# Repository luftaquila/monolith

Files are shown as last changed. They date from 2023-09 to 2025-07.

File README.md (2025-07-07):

> [!IMPORTANT]
> Monolith [v2](https://github.com/luftaquila/monolith/tree/v2) is now under development and will be released in a few months!

# monolith

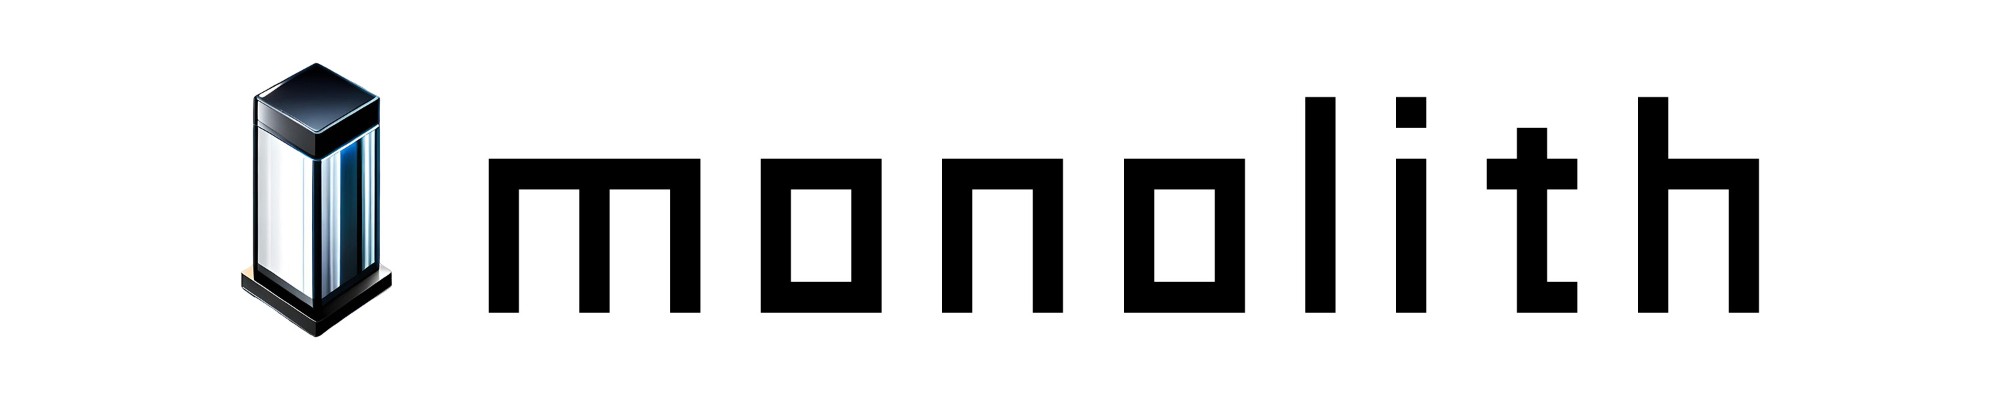
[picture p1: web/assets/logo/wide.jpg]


<div align="center">
<strong>
<samp>

[English](README.md) · [한국어](README_KO.md)

</samp>
</strong>
</div>

Monolith is an open-source DIY datalogging platform for the Student Formula and Baja.

Build your own datalogger and use the real-time telemetry and data analysis tools with ease!

### Main Features
* Various types of data supported, including CAN, acceleration, GPS, digital/analog signals and wheel speeds
* Micro SD card support
* Real-time telemetry
* Real world time tracking via RTC
* Web based data visualization and analysis tools

### [Documentation](https://github.com/luftaquila/monolith/wiki)

Monolith consists of `TMA-1` datalogger, `TMA-2` telemetry monitor and `TMA-3` data analysis tools.

<br>

## TMA-1 Datalogger
TMA-1 is an onboard device that gathers data from the car. It can record the following data:

* CAN 2.0(A/B) bus traffic
* 8-channel digital input signals
* 4-channel analog input signals
* 4-channel external wheel speed sensors (digital pulse period)
* 3-axis ±4g acceleration (ADXL345)
* GPS informations (NEO-6/7M)
* Supply voltage(LV) and internal CPU temperature
* Real world time(RTC)

Refer to the [TMA‐1 Features and Usage Guide](https://github.com/luftaquila/monolith/wiki/%5BEN%5D-TMA%E2%80%901-Features-and-Usage-Guide) for detailed explanations about each feature.

### 1-1. TMA-1 Do It Yourself!
TMA-1 is a DIY datalogger that each user buys components and builds their own device. It is designed with commercial modules and through-hole components for easy self build.

Required components and build instructions are described in the [TMA-1 DIY Guide](https://github.com/luftaquila/monolith/wiki/%5BEN%5D-TMA%E2%80%901-DIY-Guide).



### 1-2. TMA-1 Configuration Tool
This is a GUI tool that builds and uploads the firmware to the TMA-1 with configured features.

With this tool, you can activate features in the datalogger, synchronize TMA-1's clock to your computer time, and configure the networks for the telemetry.

For the detailed information, please refer to the [TMA-1 Configuration Tool Guide](https://github.com/luftaquila/monolith/wiki/%5BEN%5D-TMA%E2%80%901-Configuration-Tool-Guide).



<br><br>

## TMA-2 Telemetry monitor
TMA-2 consists of the telemetry server that TMA-1 communicates with, and the web client for real-time data monitoring.

### Server
Users do not need to set up the server individually, except in case you want your own server. TMA-1 uses the default monolith server (monolith.luftaquila.io) for the telemetry.

> The default TMA-2 server is available to the approved users only.<br>
> There are no additional fees for registration. Just send me a school and team name, your desired car ID and key to mail@luftaquila.io and that's it.

If you want to self-host your own server, follow the [TMA-2 Server Setup Guide](https://github.com/luftaquila/monolith/wiki/%5BEN%5D-TMA%E2%80%902-Server-Setup-Guide).

### Client
Real-time monitoring client is served at https://monolith.luftaquila.io/live.

Each user can set up their own UI with their preferences. It also supports the UI export and import features.

For the detailed information, please refer to the [TMA‐2 Client Usage Guide](https://github.com/luftaquila/monolith/wiki/%5BEN%5D-TMA%E2%80%902-Client-Usage-Guide).



<br><br>

## TMA-3 Log Translator and Data Analysis Tool
TMA-1 datalogger stores the log in the SD card in a binary format, according to the predefined [protocol](https://github.com/luftaquila/monolith/wiki/%5BEN%5D-Log-Protocol).

TMA-3 is a set of tools that can translate binary logs to human-readable format(JSON/CSV) and visualize the collected data into graphs and a map.

All these features are web application services that can be instantly accessed at https://monolith.luftaquila.io.

For the detailed information, please refer to the [TMA‐3 Data Analysis Tool Guide](https://github.com/luftaquila/monolith/wiki/%5BEN%5D-TMA%E2%80%903-Data-Analysis-Tool-Guide).



<br><br>

## Others
The name of the project was inspired by Arthur C. Clark's novel *2001: A Space Odyssey*.

Monolith received the Gold Award in the *2023 KSAE KSAE Baja/Formula/EV* Technology Idea section and the Best Award in the *2022-2 Ajou University SW Convergence Challenge*.



<br><br>

## Sponsors


Prototype PCB of the TMA-1 was sponsored by [PCBWay](https://www.pcbway.com/).

<br>

## LICENSE
```
"THE BEERWARE LICENSE" (Revision 42):
LUFT-AQUILA wrote this project. As long as you retain this notice,
you can do whatever you want with this stuff. If we meet someday,
and you think this stuff is worth it, you can buy me a beer in return.
```

<br>

<hr>

<picture>
  <source media="(prefers-color-scheme: dark)" srcset="https://api.star-history.com/svg?repos=luftaquila/monolith&type=Date&theme=dark" />
  <source media="(prefers-color-scheme: light)" srcset="https://api.star-history.com/svg?repos=luftaquila/monolith&type=Date" />
  Star History Chart
</picture>

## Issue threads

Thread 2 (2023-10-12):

Broken log data is transferred

luftaquila, 2023-10-12:
After a random period of time since TMA-1 boot, TMA-2 server is receiving misaligned log packets.

example 1) timestamp 4847271
`a7f64900030200eb0000000000000000` to `000bf749000302005000000000000000`

example 2) timestamp 854379
`6b090d0003030049ffffc20200000000` to `00ca090d00030200e500000000000000`

One byte is inserted in front of the log packet and causing parse failure.

After a long time of operation, there are two invalid bytes in front of the log byte.

They looks like the last bytes of the previous log packet in the buffer.

example logs:
```
{"channel":"default","data":{"checksum":true,"datetime":null,"key":"ACCELEROMETER_DATA","level":"INFO","parsed":{"x":-0.0078125,"y":0.0703125,"z":1.046875},"raw":[255,255,9,0,134,0,0,0],"source":"ACCELEROMETER","timestamp":4847171,"value":575526273023},"id":"3XQem_L0JusMWR-oAAAD","ip":"192.168.0.1","level":"info","message":"REPORT","raw":"43f6490003050017ffff090086000000","timestamp":"2023-10-12 20:10:22.187"}
{"channel":"default","data":{"checksum":true,"datetime":null,"key":"DIGITAL_DATA","level":"INFO","parsed":{"DIN0":0,"DIN1":0,"DIN2":0,"DIN3":0,"DIN4":0,"DIN5":0,"DIN6":0,"DIN7":0},"raw":[0,0,0,0,0,0,0,0],"source":"DIGITAL","timestamp":4847271,"value":0},"id":"3XQem_L0JusMWR-oAAAD","ip":"192.168.0.1","level":"info","message":"REPORT","raw":"a7f64900030200eb0000000000000000","timestamp":"2023-10-12 20:10:22.274"}
{"channel":"default","data":"TypeError: Cannot read properties of undefined (reading 'name')","id":"3XQem_L0JusMWR-oAAAD","ip":"192.168.0.1","level":"error","message":"PARSE FAILED","raw":"000bf749000302005000000000000000","timestamp":"2023-10-12 20:10:22.377"}
{"channel":"default","data":"TypeError: Cannot read properties of undefined (reading 'name')","id":"3XQem_L0JusMWR-oAAAD","ip":"192.168.0.1","level":"error","message":"PARSE FAILED","raw":"0010f7490003030005ffffaf02000000","timestamp":"2023-10-12 20:10:22.384"}
```

```
{"channel":"default","data":{"checksum":true,"datetime":null,"key":"DIGITAL_DATA","level":"INFO","parsed":{"DIN0":0,"DIN1":0,"DIN2":0,"DIN3":0,"DIN4":0,"DIN5":0,"DIN6":0,"DIN7":0},"raw":[0,0,0,0,0,0,0,0],"source":"DIGITAL","timestamp":854374,"value":0},"id":"OwGVzEw9kGCz46YnAAAl","ip":"192.168.0.1","level":"info","message":"REPORT","raw":"66090d00030200810000000000000000","timestamp":"2023-10-13 00:07:33.290"}
{"channel":"default","data":{"checksum":true,"datetime":null,"key":"ANALOG_SYS","level":"INFO","parsed":{"CPU_TEMP":6553.5,"INPUT_VOLTAGE":4.551501831501831},"raw":[255,255,194,2,0,0,0,0],"source":"ANALOG","timestamp":854379,"value":46333951},"id":"OwGVzEw9kGCz46YnAAAl","ip":"192.168.0.1","level":"info","message":"REPORT","raw":"6b090d0003030049ffffc20200000000","timestamp":"2023-10-13 00:07:33.297"}
{"channel":"default","data":"TypeError: Cannot read properties of undefined (reading 'name')","id":"OwGVzEw9kGCz46YnAAAl","ip":"192.168.0.1","level":"error","message":"PARSE FAILED","raw":"00ca090d00030200e500000000000000","timestamp":"2023-10-13 00:07:33.384"}
{"channel":"default","data":"TypeError: Cannot read properties of undefined (reading 'name')","id":"OwGVzEw9kGCz46YnAAAl","ip":"192.168.0.1","level":"error","message":"PARSE FAILED","raw":"00ca090d000303019d8a00af0204046f","timestamp":"2023-10-13 00:07:33.392"}
```

luftaquila, 2023-10-13:
This is a problem of ESP32, not STM32.

I2C bus is transmitting a normal log with fine align, while server is receiving misaligned data.

I2C records:
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

Server logs:
```
{"channel":"default","data":"TypeError: Cannot read properties of undefined (reading 'name')","id":"5eaiSrF9_m9ZKYgVAAAs","ip":"192.168.0.1","level":"error","message":"PARSE FAILED","raw":"0444ab5b00030500cef7ff0000860000","timestamp":"2023-10-13 19:43:26.401"}
{"channel":"default","data":"TypeError: Cannot read properties of undefined (reading 'name')","id":"5eaiSrF9_m9ZKYgVAAAs","ip":"192.168.0.1","level":"error","message":"PARSE FAILED","raw":"00a8ab5b00030200b300000000000000","timestamp":"2023-10-13 19:43:26.486"}
{"channel":"default","data":"TypeError: Cannot read properties of undefined (reading 'name')","id":"5eaiSrF9_m9ZKYgVAAAs","ip":"192.168.0.1","level":"error","message":"PARSE FAILED","raw":"00a8ab5b00030301a57700e1020e0480","timestamp":"2023-10-13 19:43:26.493"}
{"channel":"default","data":"TypeError: Cannot read properties of undefined (reading 'name')","id":"5eaiSrF9_m9ZKYgVAAAs","ip":"192.168.0.1","level":"error","message":"PARSE FAILED","raw":"04a8ab5b0003050033f7ff0000870000","timestamp":"2023-10-13 19:43:26.501"}
{"channel":"default","data":"TypeError: Cannot read properties of undefined (reading 'name')","id":"5eaiSrF9_m9ZKYgVAAAs","ip":"192.168.0.1","level":"error","message":"PARSE FAILED","raw":"000cac5b000302001800000000000000","timestamp":"2023-10-13 19:43:26.586"}
{"channel":"default","data":"TypeError: Cannot read properties of undefined (reading 'name')","id":"5eaiSrF9_m9ZKYgVAAAs","ip":"192.168.0.1","level":"error","message":"PARSE FAILED","raw":"000cac5b00030301a5b2002e0324047c","timestamp":"2023-10-13 19:43:26.593"}
{"channel":"default","data":"TypeError: Cannot read properties of undefined (reading 'name')","id":"5eaiSrF9_m9ZKYgVAAAs","ip":"192.168.0.1","level":"error","message":"PARSE FAILED","raw":"040eac5b000305009af7ff0000870000","timestamp":"2023-10-13 19:43:26.601"}
{"channel":"default","data":"TypeError: Cannot read properties of undefined (reading 'name')","id":"5eaiSrF9_m9ZKYgVAAAs","ip":"192.168.0.1","level":"error","message":"PARSE FAILED","raw":"0070ac5b000302007c00000000000000","timestamp":"2023-10-13 19:43:26.687"}
{"channel":"default","data":"TypeError: Cannot read properties of undefined (reading 'name')","id":"5eaiSrF9_m9ZKYgVAAAs","ip":"192.168.0.1","level":"error","message":"PARSE FAILED","raw":"0070ac5b00030301af8000bc02ca0322","timestamp":"2023-10-13 19:43:26.694"}
{"channel":"default","data":"TypeError: Cannot read properties of undefined (reading 'name')","id":"5eaiSrF9_m9ZKYgVAAAs","ip":"192.168.0.1","level":"error","message":"PARSE FAILED","raw":"0470ac5b00030500fcf7ff0000870000","timestamp":"2023-10-13 19:43:26.701"}
```

luftaquila, 2023-10-13:
Proved no misaligning happens while running alive for 10,000,000ms(166min)

Closed 2023-10-13.

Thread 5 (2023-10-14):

Wrong internal CPU temperature measurement

luftaquila, 2023-10-14:
In `ANALOG_SYS` log data, internal cpu temperature is always stored [255, 255] when TMA-1 is powered by 12V VIN input, causing 6553.5°C CPU temperature.

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

But when TMA-1 is powered by USB-C in ESP32 board, it is stored correctly.

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

luftaquila, 2023-10-29:
seems like problem of casting in internal temperature calculation at [here](https://github.com/luftaquila/monolith/blob/main/device/TMA-1/Core/Src/adc.c#L35C5-L35C114)

```c
adc_sys_value[0] = (uint16_t)(((110.0 - 30) * (adc_sys_value[0] - TS_CAL1) / (TS_CAL2 - TS_CAL1) + 30) * 10);
```

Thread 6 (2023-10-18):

Poor TMA-3 graph viewer performance

luftaquila, 2023-10-18:
TMA-3 is currently using Chart.js for graph viewer, which has poor performance for large data points

Replace Chart.js to [Dygraphs](https://dygraphs.com/) for better graph performance.

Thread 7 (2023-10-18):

Missing support for CAN bitwise data view

luftaquila, 2023-10-18:
Currently TMA-2/3 does not support CAN bitwise data parsing and favorite data feature, while UI supports.

luftaquila, 2023-10-19:
Decided to drop support for CAN favorite data feature (ee746b1bb2287862ee7f3cd8c8767a61d54dbb44)

Closed 2025-08-12.

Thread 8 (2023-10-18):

Fixed CAN baud rate

luftaquila, 2023-10-18:
Current TMA-1 has 250 kbit/s fixed CAN baud rate.

Support for flexible baud rate: 125 kbit/s, 250 kbit/s, 500 kbit/s, 1Mbit/s is needed.

Closed 2023-10-19.

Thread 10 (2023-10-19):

Wireless log file transmit feature

luftaquila, 2023-10-19:
Currently, the only way to analyze data saved in the TMA-1's SD card is to eject and put the card into the computer, and upload it to the TMA-3.

Ejecting a card is the most annoying step of the procedure. Anyway, TMA-1 has a wireless internet connection.

So TMA-1 can transfer a saved log file to the TMA-3 over wireless when requested.

Feature idea:
1. TMA-3 requests a log file list
2. TMA-2 server requests TMA-1 to send a log file list
3. ESP32 receives the request and informs STM32 about the request (by an additional wire `ESP_REQ`)
4. STM32 enters log transmitting mode, aborting all data logging job and disabling all interrupts
5. STM32 reads the SD card and transmits the log file list to ESP32 via I2C
6. ESP32 hand out the log file list to TMA-2, and TMA-2 passes the list to TMA-3
7. A specific log file transfer request made by TMA-3 is sent to ESP32 through the TMA-2
8. ESP32 requests STM32 to transmit the specific log file
9. STM32 transmit the log file to ESP32 via I2C. The log file will be sliced into chunks since ESP32 cannot hold the whole log file in a memory.
10.  ESP32 transfers the log file chunk to TMA-2
11. TMA-2 assembles the log file and pass it to the TMA-3

luftaquila, 2025-08-12:
Done in v2

Closed 2025-08-12.

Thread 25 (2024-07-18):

ESP32 firmware build fails with esp32-arduino core package version >= 3.0.0

luftaquila, 2024-07-18:
Link error occurs while building esp32 firmware. https://github.com/luftaquila/monolith/discussions/24

Build fails with following versions:
```
Used library        Version Path
Wire                3.0.3   C:\monolith\builder\toolchain\arduino\data\packages\esp32\hardware\esp32\3.0.3\libraries\Wire
WiFi                3.0.3   C:\monolith\builder\toolchain\arduino\data\packages\esp32\hardware\esp32\3.0.3\libraries\WiFi
Networking          3.0.3   C:\monolith\builder\toolchain\arduino\data\packages\esp32\hardware\esp32\3.0.3\libraries\Network
RingBuffer          1.0.5   C:\monolith\builder\toolchain\arduino\user\libraries\RingBuffer
ArduinoJson         7.1.0   C:\monolith\builder\toolchain\arduino\user\libraries\ArduinoJson
WebSockets          2.4.1   C:\monolith\builder\toolchain\arduino\user\libraries\WebSockets
NetworkClientSecure 3.0.3   C:\monolith\builder\toolchain\arduino\data\packages\esp32\hardware\esp32\3.0.3\libraries\NetworkClientSecure

Used platform Version Path
esp32:esp32   3.0.3   C:\monolith\builder\toolchain\arduino\data\packages\esp32\hardware\esp32\3.0.3
```

Build succeed with following versions:
```
Used library     Version Path
Wire             2.0.0   C:\monolith\builder\toolchain\arduino\data\packages\esp32\hardware\esp32\2.0.17\libraries\Wire
WiFi             2.0.0   C:\monolith\builder\toolchain\arduino\data\packages\esp32\hardware\esp32\2.0.17\libraries\WiFi
RingBuffer       1.0.5   C:\monolith\builder\toolchain\arduino\user\libraries\RingBuffer
ArduinoJson      7.1.0   C:\monolith\builder\toolchain\arduino\user\libraries\ArduinoJson
WebSockets       2.4.1   C:\monolith\builder\toolchain\arduino\user\libraries\WebSockets
WiFiClientSecure 2.0.0   C:\monolith\builder\toolchain\arduino\data\packages\esp32\hardware\esp32\2.0.17\libraries\WiFiClientSecure

Used platform Version Path
esp32:esp32   2.0.17  C:\monolith\builder\toolchain\arduino\data\packages\esp32\hardware\esp32\2.0.17
```

Not sure which side causes the error, `esp32-arduino` or `arduino-cli`.

Closed 2024-07-18.

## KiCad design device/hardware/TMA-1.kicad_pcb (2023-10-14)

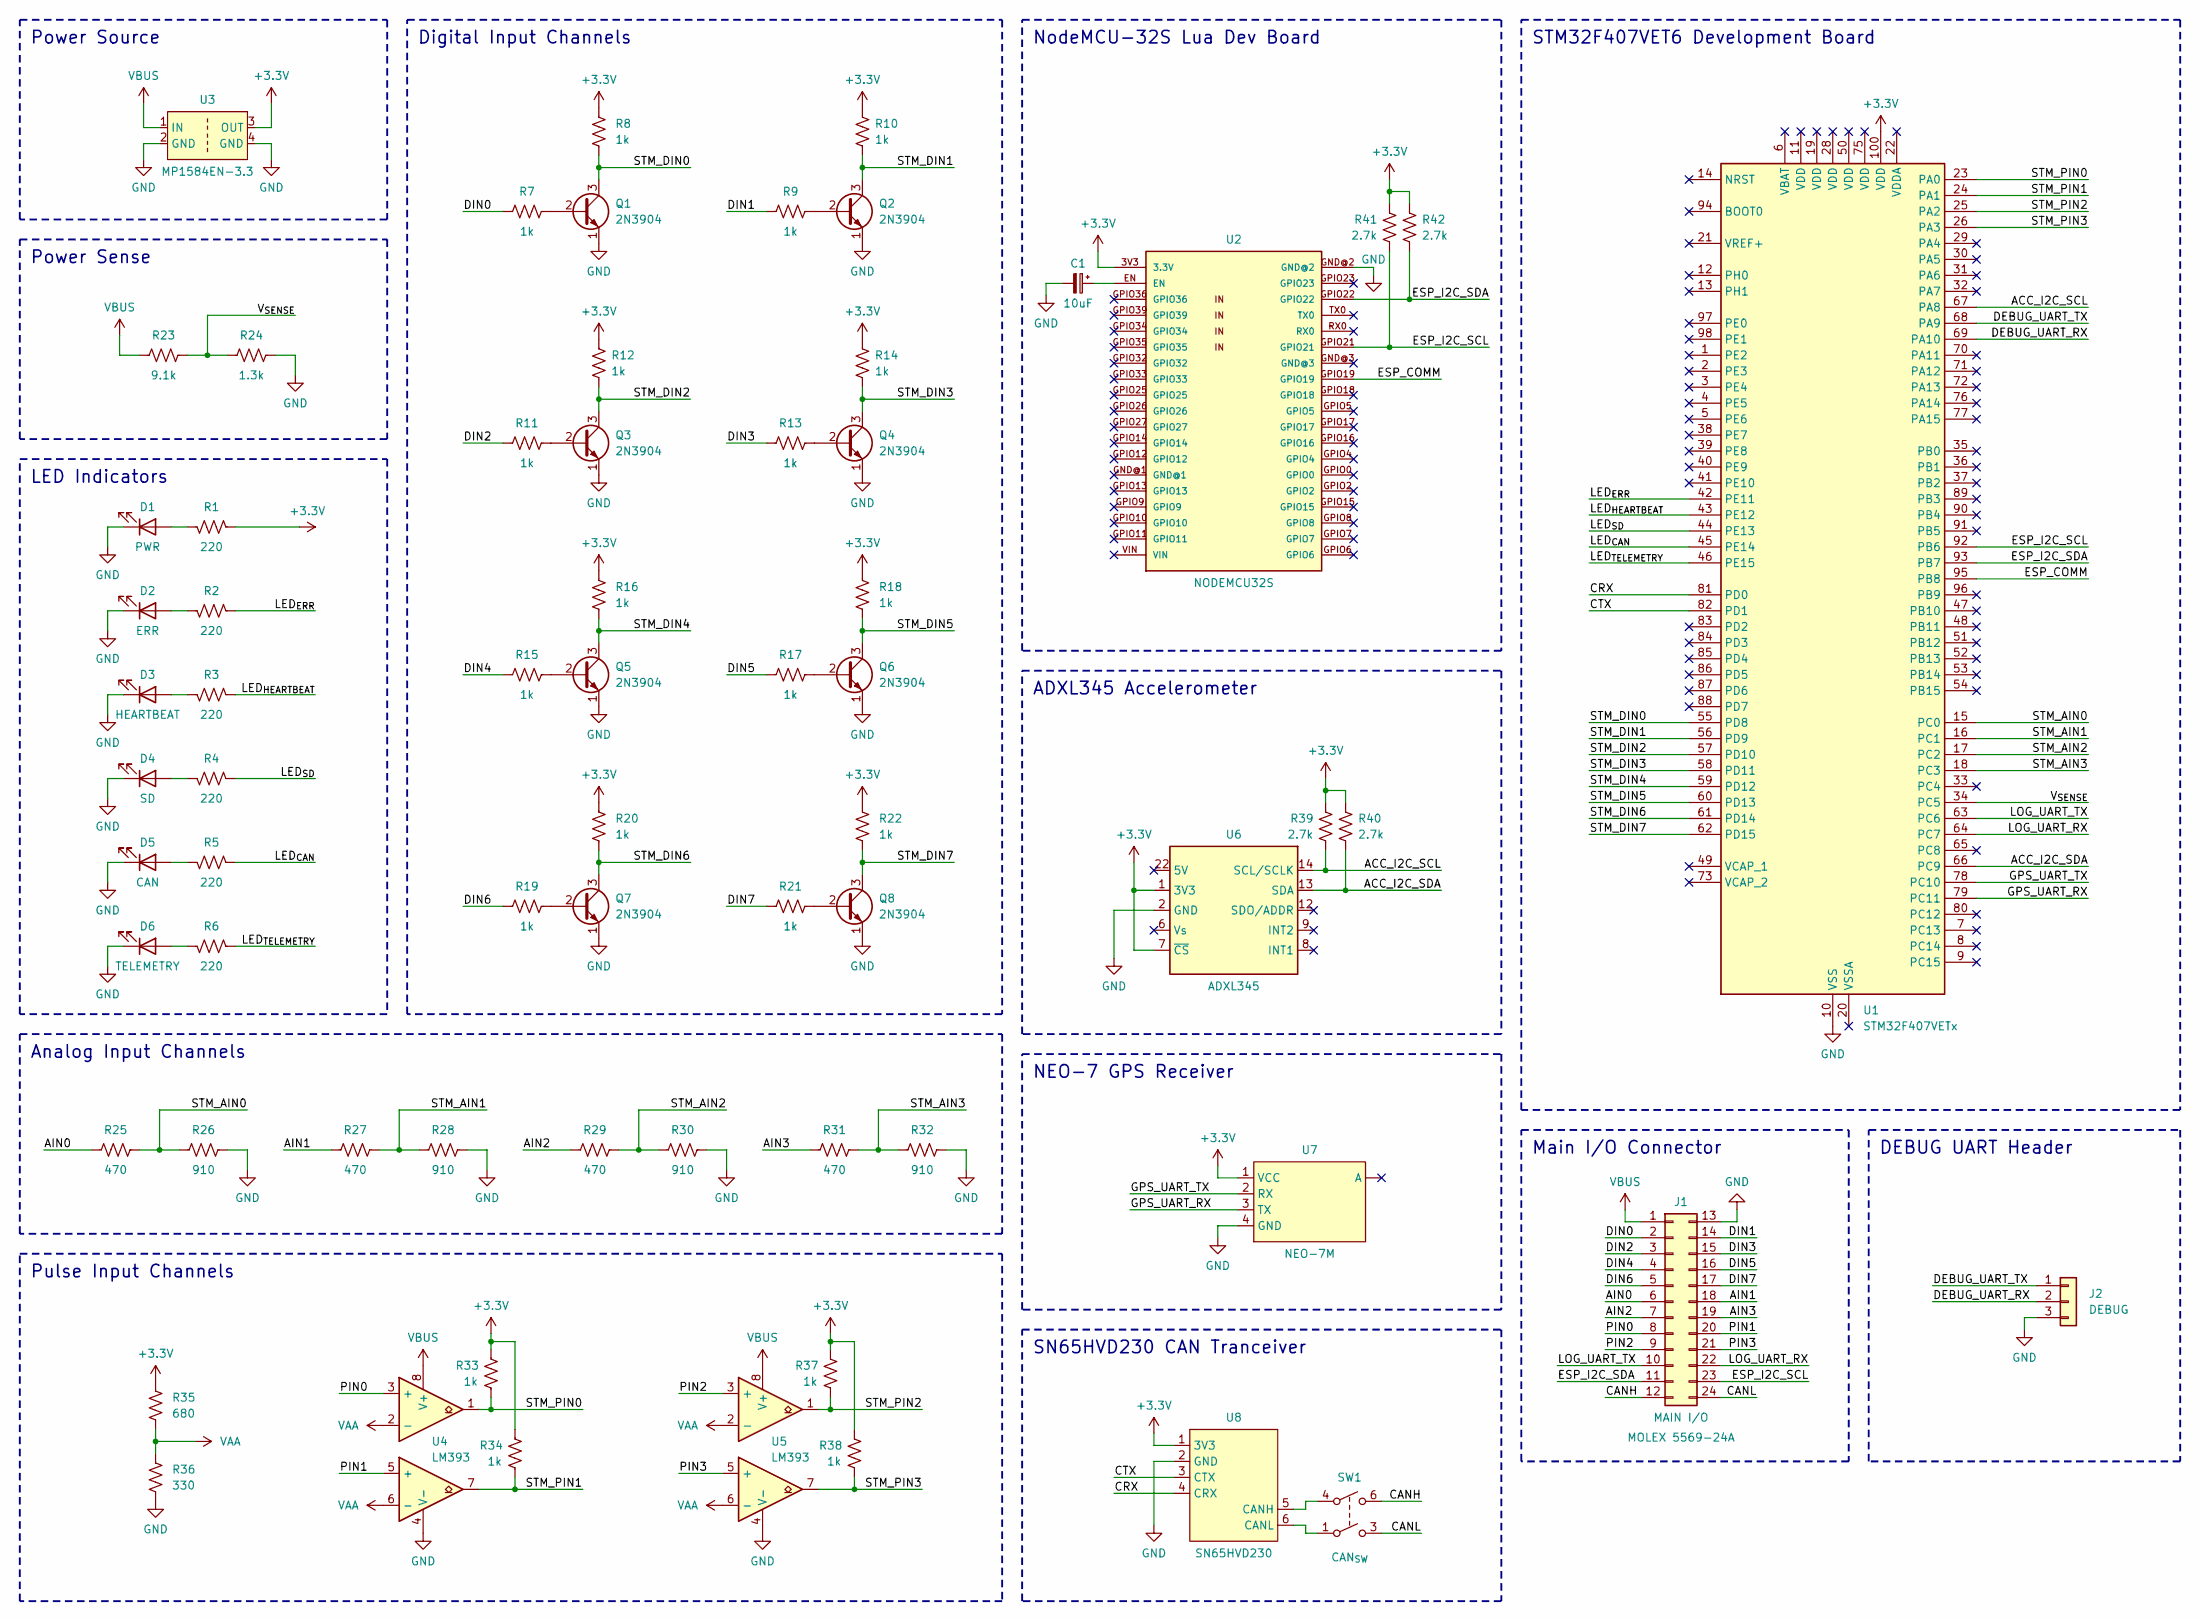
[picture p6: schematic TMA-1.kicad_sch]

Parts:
C1: 10uF; CP_Radial_D5.0mm_P2.00mm
D1: PWR; LED_D5.0mm_FlatTop
D2: ERR; LED_D5.0mm_FlatTop
D3: HEARTBEAT; LED_D5.0mm_FlatTop
D4: SD; LED_D5.0mm_FlatTop
D5: CAN; LED_D5.0mm_FlatTop
D6: TELEMETRY; LED_D5.0mm_FlatTop
J1: MAIN I/O; Molex_Mini-Fit_Jr_5569-24A1_2x12_P4.20mm_Horizontal
J2: DEBUG; PinHeader_1x03_P2.54mm_Vertical
Q1, Q2, Q3, Q4, Q5, Q6, Q7, Q8: 2N3904; TO-92_Inline_Wide
R1, R2, R3, R4, R5, R6: 220; R_Axial_DIN0207_L6.3mm_D2.5mm_P10.16mm_Horizontal
R7, R8, R9, R10, R11, R12, R13, R14, R15, R16, R17, R18, R19, R20, R21, R22, R33, R34, R37, R38: 1k; R_Axial_DIN0207_L6.3mm_D2.5mm_P10.16mm_Horizontal
R23: 9.1k; R_Axial_DIN0207_L6.3mm_D2.5mm_P10.16mm_Horizontal
R24: 1.3k; R_Axial_DIN0207_L6.3mm_D2.5mm_P10.16mm_Horizontal
R25, R27, R29, R31: 470; R_Axial_DIN0207_L6.3mm_D2.5mm_P10.16mm_Horizontal
R26, R28, R30, R32: 910; R_Axial_DIN0207_L6.3mm_D2.5mm_P10.16mm_Horizontal
R35: 680; R_Axial_DIN0207_L6.3mm_D2.5mm_P10.16mm_Horizontal
R36: 330; R_Axial_DIN0207_L6.3mm_D2.5mm_P10.16mm_Horizontal
R39, R40, R41, R42: 2.7k; R_Axial_DIN0207_L6.3mm_D2.5mm_P10.16mm_Horizontal
SW1: CAN_{SW}; TOGGLE_SWITCH
U1: STM32F407VETx; STM32F407_HOLDER
U2: NODEMCU32S
U3: MP1584EN-3.3; MP1584EN_MODULE
U4, U5: LM393; DIP-8_W7.62mm
U6: ADXL345; ADXL345_MODULE
U7: NEO-7M; GPS_MODULE
U8: SN65HVD230; SN65HVD230_MODULE

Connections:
+3.3V: R1.1, R8.1, R10.1, R12.1, R14.1, R16.1, R18.1, R20.1, R22.1, R33.1, R34.1, R35.1, R37.1, R38.1, R39.1, R40.1, R41.1, R42.1, U1.100 (VDD), U2.3V3 (3.3V), U3.3 (OUT), U6.1 (3V3), U6.7 (~CS), U7.1 (VCC), U8.1 (3V3)
/ACC_I2C_SCL: R39.2, U1.67 (PA8), U6.14 (SCL/SCLK)
/ACC_I2C_SDA: R40.2, U1.66 (PC9), U6.13 (SDA)
/AIN0: J1.6, R25.1
/AIN1: J1.18, R27.1
/AIN2: J1.7, R29.1
/AIN3: J1.19, R31.1
/CANH: J1.12, SW1.6
/CANL: J1.24, SW1.3
/CRX: U1.81 (PD0), U8.4 (CRX)
/CTX: U1.82 (PD1), U8.3 (CTX)
/DEBUG_UART_RX: J2.2, U1.69 (PA10)
/DEBUG_UART_TX: J2.1, U1.68 (PA9)
/DIN0: J1.2, R7.1
/DIN1: J1.14, R9.1
/DIN2: J1.3, R11.1
/DIN3: J1.15, R13.1
/DIN4: J1.4, R15.1
/DIN5: J1.16, R17.1
/DIN6: J1.5, R19.1
/DIN7: J1.17, R21.1
/ESP_COMM: U1.95 (PB8), U2.GPIO19
/ESP_I2C_SCL: J1.23, R41.2, U1.92 (PB6), U2.GPIO21
/ESP_I2C_SDA: J1.11, R42.2, U1.93 (PB7), U2.GPIO22
/GPS_UART_RX: U1.79 (PC11), U7.3 (TX)
/GPS_UART_TX: U1.78 (PC10), U7.2 (RX)
/LED_{CAN}: R5.1, U1.45 (PE14)
/LED_{ERR}: R2.1, U1.42 (PE11)
/LED_{HEARTBEAT}: R3.1, U1.43 (PE12)
/LED_{SD}: R4.1, U1.44 (PE13)
/LED_{TELEMETRY}: R6.1, U1.46 (PE15)
/LOG_UART_RX: J1.22, U1.64 (PC7)
/LOG_UART_TX: J1.10, U1.63 (PC6)
/PIN0: J1.8, U4.3 (+)
/PIN1: J1.20, U4.5 (+)
/PIN2: J1.9, U5.3 (+)
/PIN3: J1.21, U5.5 (+)
/STM_AIN0: R25.2, R26.1, U1.15 (PC0)
/STM_AIN1: R27.2, R28.1, U1.16 (PC1)
/STM_AIN2: R29.2, R30.1, U1.17 (PC2)
/STM_AIN3: R31.2, R32.1, U1.18 (PC3)
/STM_DIN0: Q1.3 (C), R8.2, U1.55 (PD8)
/STM_DIN1: Q2.3 (C), R10.2, U1.56 (PD9)
/STM_DIN2: Q3.3 (C), R12.2, U1.57 (PD10)
/STM_DIN3: Q4.3 (C), R14.2, U1.58 (PD11)
/STM_DIN4: Q5.3 (C), R16.2, U1.59 (PD12)
/STM_DIN5: Q6.3 (C), R18.2, U1.60 (PD13)
/STM_DIN6: Q7.3 (C), R20.2, U1.61 (PD14)
/STM_DIN7: Q8.3 (C), R22.2, U1.62 (PD15)
/STM_PIN0: R33.2, U1.23 (PA0), U4.1
/STM_PIN1: R34.2, U1.24 (PA1), U4.7
/STM_PIN2: R37.2, U1.25 (PA2), U5.1
/STM_PIN3: R38.2, U1.26 (PA3), U5.7
/V_{SENSE}: R23.2, R24.1, U1.34 (PC5)
GND: C1.2, D1.1 (K), D2.1 (K), D3.1 (K), D4.1 (K), D5.1 (K), D6.1 (K), J1.13, J2.3, Q1.1 (E), Q2.1 (E), Q3.1 (E), Q4.1 (E), Q5.1 (E), Q6.1 (E), Q7.1 (E), Q8.1 (E), R24.2, R26.2, R28.2, R30.2, R32.2, R36.2, U1.10 (VSS), U1.27 (VSS), U1.74 (VSS), U1.99 (VSS), U2.GND@2, U3.2 (GND), U3.4 (GND), U4.4 (V-), U5.4 (V-), U6.2 (GND), U7.4 (GND), U8.2 (GND)
unnamed: C1.1, U2.EN
unnamed: D1.2 (A), R1.2
unnamed: D2.2 (A), R2.2
unnamed: D3.2 (A), R3.2
unnamed: D4.2 (A), R4.2
unnamed: D5.2 (A), R5.2
unnamed: D6.2 (A), R6.2
unnamed: Q1.2 (B), R7.2
unnamed: Q2.2 (B), R9.2
unnamed: Q3.2 (B), R11.2
unnamed: Q4.2 (B), R13.2
unnamed: Q5.2 (B), R15.2
unnamed: Q6.2 (B), R17.2
unnamed: Q7.2 (B), R19.2
unnamed: Q8.2 (B), R21.2
unnamed: SW1.4, U8.5 (CANH)
unnamed: SW1.1, U8.6 (CANL)
VAA: R35.2, R36.1, U4.2 (-), U4.6 (-), U5.2 (-), U5.6 (-)
VBUS: J1.1, R23.1, U3.1 (IN), U4.8 (V+), U5.8 (V+)

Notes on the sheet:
LED Indicators
Power Source
Main I/O Connector
Digital Input Channels
STM32F407VET6 Development Board
DEBUG UART Header
NEO-7 GPS Receiver
Power Sense
Analog Input Channels
Pulse Input Channels
ADXL345 Accelerometer
SN65HVD230 CAN Tranceiver
NodeMCU-32S Lua Dev Board

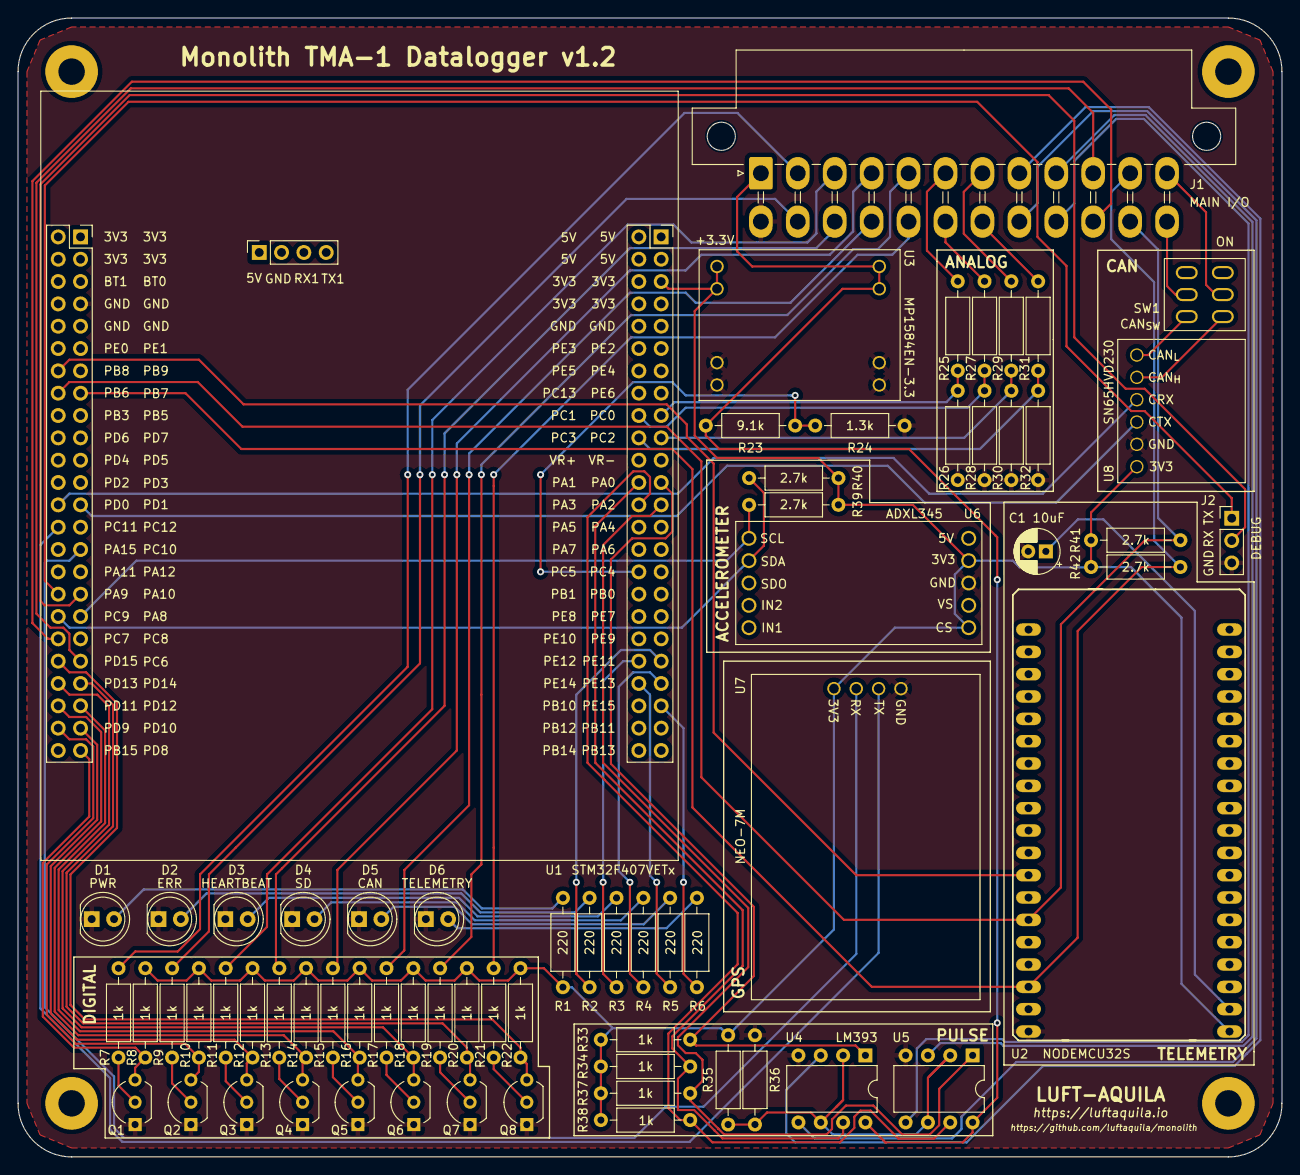
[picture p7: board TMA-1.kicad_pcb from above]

Board: 2 copper layers, 143.8 x 129.5 mm, 68 parts (0 on the bottom side), 74 nets.

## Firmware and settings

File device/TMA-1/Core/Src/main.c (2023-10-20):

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
/* Includes ------------------------------------------------------------------*/
#include "main.h"
#include "adc.h"
#include "can.h"
#include "dma.h"
#include "fatfs.h"
#include "i2c.h"
#include "rtc.h"
#include "sdio.h"
#include "tim.h"
#include "usart.h"
#include "gpio.h"

/* USER CODE BEGIN Includes */
#include "logger.h"
#include "types.h"
#include "ringbuffer.h"
/* USER CODE END Includes */

/* USER CODE BEGIN PD */
extern int SYS_LOG(LOG_LEVEL level, LOG_SOURCE source, int key);

/* USER CODE END PD */

/* USER CODE BEGIN PM */
extern uint32_t to_uint(uint8_t *str, char garbage);
extern uint32_t drop_point(uint8_t *str);
/* USER CODE END PM */


/* USER CODE BEGIN PV */

// system log
FIL logfile;
LOG syslog;

// system state
SYSTEM_STATE sys_state;

// timer alarm flag
uint32_t timer_flag = 0;

// rtc buffer
uint8_t rtc[25]; // YYYY-MM-DD-HH-MM-SS

// SD card write buffer
ring_buffer_t SD_BUFFER;
uint8_t SD_BUFFER_ARR[1 << 12]; // 4KB

// serial log output buffer
#ifdef ENABLE_SERIAL
uint32_t serial_flag = 0;
ring_buffer_t SERIAL_BUFFER;
uint8_t SERIAL_BUFFER_ARR[1 << 14]; // 16KB
#endif

// telemetry transmission flag and buffer
#ifdef ENABLE_TELEMETRY
uint32_t telemetry_flag = 0;
uint32_t handshake_flag = 0;
ring_buffer_t TELEMETRY_BUFFER;
uint8_t TELEMETRY_BUFFER_ARR[1 << 14]; // 16KB
#endif

// CAN RX header and buffer
#ifdef ENABLE_MONITOR_CAN
CAN_RxHeaderTypeDef can_rx_header;
uint8_t can_rx_data[8];
#endif

// adc conversion buffers
uint32_t adc_flag = 0;
uint32_t adc_sys_value[2] = { 0, };
#ifdef ENABLE_MONITOR_ANALOG
uint32_t adc_ain_value[ADC_COUNT] = { 0, };
#endif

// timer pulse input capture flag and data
#ifdef ENABLE_MONITOR_PULSE
uint32_t pulse_flag = 0;
uint32_t pulse_value[PULSE_CH_COUNT] = { 0, }; // microsecond
uint32_t pulse_buffer_0[PULSE_CH_COUNT] = { 0, };
uint32_t pulse_buffer_1[PULSE_CH_COUNT] = { 0, };
#endif

// accelerometer receive buffer
#ifdef ENABLE_MONITOR_ACCELEROMETER
uint32_t accelerometer_flag = false;
uint8_t accelerometer_value[6];
#endif

// GPS receive flag and buffer
#ifdef ENABLE_MONITOR_GPS
uint32_t gps_flag = false;
uint8_t gps_data[1 << 7]; // 128B
#endif
/* USER CODE END PV */

void SystemClock_Config(void);
/* USER CODE BEGIN PFP */
__attribute__((weak)) void _close(void){}
__attribute__((weak)) void _lseek(void){}
__attribute__((weak)) void _read(void){}

void GPS_PARSE(void);
/* USER CODE END PFP */

/* USER CODE BEGIN 0 */
int _write(int file, uint8_t *ptr, int len) {
  HAL_UART_Transmit(UART_DEBUG, (uint8_t *)ptr, (uint16_t)len, 30);
  return (len);
}
/* USER CODE END 0 */

/**
  * @brief  The application entry point.
  * @retval int
  */
int main(void)
{
  /* MCU Configuration--------------------------------------------------------*/

  /* Reset of all peripherals, Initializes the Flash interface and the Systick. */
  HAL_Init();

  /* Configure the system clock */
  SystemClock_Config();

  /* Initialize all configured peripherals */
  MX_GPIO_Init();
  MX_DMA_Init();
  MX_ADC1_Init();
  MX_ADC2_Init();
  MX_RTC_Init();
  MX_TIM1_Init();
  MX_TIM5_Init();
  MX_CAN1_Init();
  MX_I2C1_Init();
  MX_I2C3_Init();
  MX_SDIO_SD_Init();
  MX_USART1_UART_Init();
  MX_USART3_UART_Init();
  MX_FATFS_Init();
  MX_USART6_UART_Init();
  /* USER CODE BEGIN 2 */

  /********** CORE SYSTEM STARTUP **********/
  int ret;
  DEBUG_MSG("[%8lu] [INF] core system is in startup\r\n", HAL_GetTick());


  /********** RTC boot time check **********/
  DATETIME boot;
  RTC_READ(&boot);
  DEBUG_MSG("[%8lu] [INF] RTC time is 20%02d-%02d-%02d %02d:%02d:%02d\r\n", HAL_GetTick(), boot.year, boot.month, boot.date, boot.hour, boot.minute, boot.second);


  /********** SD card initialization **********/
  ret = SD_SETUP(&boot);

  if (ret == SYS_OK) {
    sys_state.SD = true;
    HAL_GPIO_WritePin(GPIOE, LED_SD_Pin, GPIO_PIN_SET);

    SYS_LOG(LOG_INFO, SYS, SYS_SD_INIT);

    DEBUG_MSG("[%8lu] [ OK] SD card setup\r\n", HAL_GetTick());
  } else {
    sys_state.SD = false;
    HAL_GPIO_WritePin(GPIOE, LED_SD_Pin, GPIO_PIN_RESET);

    syslog.value[0] = (uint8_t)ret;
    SYS_LOG(LOG_ERROR, SYS, SYS_SD_INIT);

    DEBUG_MSG("[%8lu] [ERR] SD card setup failed: %d\r\n", HAL_GetTick(), ret);
  }


  /********** core system initialization **********/
  HAL_GPIO_WritePin(GPIOA, LED_ONBOARD_0_Pin, GPIO_PIN_RESET);
  HAL_GPIO_WritePin(GPIOA, LED_ONBOARD_1_Pin, GPIO_PIN_RESET);
  HAL_GPIO_WritePin(GPIOE, LED_CUSTOM_0_Pin, GPIO_PIN_RESET);
  HAL_GPIO_WritePin(GPIOE, LED_CUSTOM_1_Pin, GPIO_PIN_RESET);

  sys_state.ERR = false;
  sys_state.CAN = false;
  sys_state.TELEMETRY = false;

  HAL_GPIO_WritePin(GPIOE, LED_ERR_Pin, GPIO_PIN_RESET);
  HAL_GPIO_WritePin(GPIOE, LED_HEARTBEAT_Pin, GPIO_PIN_SET);
  HAL_GPIO_WritePin(GPIOE, LED_CAN_Pin, GPIO_PIN_RESET);
  HAL_GPIO_WritePin(GPIOE, LED_TELEMETRY_Pin, GPIO_PIN_RESET);

  // RTC time sync by UART
  HAL_UART_Receive_IT(UART_DEBUG, rtc, 20);

  SYS_LOG(LOG_INFO, SYS, SYS_CORE_INIT);

  DEBUG_MSG("[%8lu] [ OK] core system setup\r\n", HAL_GetTick());


  /********** UART log output port initialization **********/
#ifdef ENABLE_SERIAL
  ret = SERIAL_SETUP();

  if (ret == SYS_OK) {
    SYS_LOG(LOG_INFO, SYS, SYS_SERIAL_INIT);

    DEBUG_MSG("[%8lu] [ OK] serial log output port setup\r\n", HAL_GetTick());
  } else {
    syslog.value[0] = (uint8_t)ret;
    SYS_LOG(LOG_ERROR, SYS, SYS_SERIAL_INIT);

    DEBUG_MSG("[%8lu] [ERR] serial log output port setup failed: %d\r\n", HAL_GetTick(), ret);
  }
#endif


  /********** ESP32 telemetry initialization **********/
#ifdef ENABLE_TELEMETRY
  ret = TELEMETRY_SETUP();

  if (ret == SYS_OK) {
    sys_state.TELEMETRY = true;

    // flash 3 times
    HAL_GPIO_WritePin(GPIOE, LED_TELEMETRY_Pin, GPIO_PIN_SET);
    HAL_Delay(100);
    HAL_GPIO_WritePin(GPIOE, LED_TELEMETRY_Pin, GPIO_PIN_RESET);
    HAL_Delay(100);
    HAL_GPIO_WritePin(GPIOE, LED_TELEMETRY_Pin, GPIO_PIN_SET);
    HAL_Delay(100);
    HAL_GPIO_WritePin(GPIOE, LED_TELEMETRY_Pin, GPIO_PIN_RESET);
    HAL_Delay(100);
    HAL_GPIO_WritePin(GPIOE, LED_TELEMETRY_Pin, GPIO_PIN_SET);
    HAL_Delay(100);
    HAL_GPIO_WritePin(GPIOE, LED_TELEMETRY_Pin, GPIO_PIN_RESET);

    SYS_LOG(LOG_INFO, SYS, SYS_TELEMETRY_INIT);

    DEBUG_MSG("[%8lu] [ OK] TELEMETRY setup\r\n", HAL_GetTick());
  } else {
    sys_state.TELEMETRY = false;
    HAL_GPIO_WritePin(GPIOE, LED_TELEMETRY_Pin, GPIO_PIN_RESET);

    syslog.value[0] = (uint8_t)ret;
    SYS_LOG(LOG_ERROR, SYS, SYS_TELEMETRY_INIT);

    DEBUG_MSG("[%8lu] [ERR] TELEMETRY setup failed: %d\r\n", HAL_GetTick(), ret);
  }
#endif


  /********** CAN transceiver initialization **********/
#ifdef ENABLE_MONITOR_CAN
  ret = CAN_SETUP();

  if (ret == SYS_OK) {
    sys_state.CAN = true;
    HAL_GPIO_WritePin(GPIOE, LED_CAN_Pin, GPIO_PIN_SET);

    SYS_LOG(LOG_INFO, SYS, CAN_INIT);

    DEBUG_MSG("[%8lu] [ OK] CAN transceiver setup\r\n", HAL_GetTick());
  } else {
    sys_state.CAN = false;
    HAL_GPIO_WritePin(GPIOE, LED_CAN_Pin, GPIO_PIN_RESET);

    syslog.value[0] = (uint8_t)ret;
    SYS_LOG(LOG_ERROR, SYS, CAN_INIT);

    DEBUG_MSG("[%8lu] [ERR] CAN transceiver setup failed: %d\r\n", HAL_GetTick(), ret);
  }
#endif


  /********** digital input initialization **********/
#ifdef ENABLE_MONITOR_DIGITAL
  ret = DIGITAL_SETUP();

  if (ret == SYS_OK) {
    SYS_LOG(LOG_INFO, SYS, DIGITAL_INIT);

    DEBUG_MSG("[%8lu] [ OK] digital input setup\r\n", HAL_GetTick());
  } else {
    syslog.value[0] = (uint8_t)ret;
    SYS_LOG(LOG_ERROR, SYS, DIGITAL_INIT);

    DEBUG_MSG("[%8lu] [ERR] digital input setup failed: %d\r\n", HAL_GetTick(), ret);
  }
#endif


  /********** analog input initialization **********/
#ifdef ENABLE_MONITOR_ANALOG
  ret = ANALOG_SETUP();

  if (ret == SYS_OK) {
    SYS_LOG(LOG_INFO, SYS, ANALOG_INIT);

    DEBUG_MSG("[%8lu] [ OK] analog input setup\r\n", HAL_GetTick());
  } else {
    syslog.value[0] = (uint8_t)ret;
    SYS_LOG(LOG_ERROR, SYS, ANALOG_INIT);

    DEBUG_MSG("[%8lu] [ERR] analog input setup failed: %d\r\n", HAL_GetTick(), ret);
  }
#endif


  /********** pulse input initialization **********/
#ifdef ENABLE_MONITOR_PULSE
  ret = PULSE_SETUP();

  if (ret == SYS_OK) {
    SYS_LOG(LOG_INFO, SYS, PULSE_INIT);

    DEBUG_MSG("[%8lu] [ OK] pulse input setup\r\n", HAL_GetTick());
  } else {
    syslog.value[0] = (uint8_t)ret;
    SYS_LOG(LOG_ERROR, SYS, PULSE_INIT);

    DEBUG_MSG("[%8lu] [ERR] pulse input setup failed: %d\r\n", HAL_GetTick(), ret);
  }
#endif


  /********** ADXL345 accelerometer initialization **********/
#ifdef ENABLE_MONITOR_ACCELEROMETER
  ret = ACCELEROMETER_SETUP();

  if (ret == SYS_OK) {
    SYS_LOG(LOG_INFO, SYS, ACCELEROMETER_INIT);

    DEBUG_MSG("[%8lu] [ OK] accelerometer setup\r\n", HAL_GetTick());
  } else {
    syslog.value[0] = (uint8_t)ret;
    SYS_LOG(LOG_ERROR, SYS, ACCELEROMETER_INIT);

    DEBUG_MSG("[%8lu] [ERR] accelerometer setup failed: %d\r\n", HAL_GetTick(), ret);
  }
#endif


  /********** NEO-7M GPS initialization **********/
#ifdef ENABLE_MONITOR_GPS
  ret = GPS_SETUP();

  if (ret == SYS_OK) {
    SYS_LOG(LOG_INFO, SYS, GPS_INIT);

    DEBUG_MSG("[%8lu] [ OK] GPS setup\r\n", HAL_GetTick());
  } else {
    syslog.value[0] = (uint8_t)ret;
    SYS_LOG(LOG_ERROR, SYS, GPS_INIT);

    DEBUG_MSG("[%8lu] [ERR] GPS setup failed: %d\r\n", HAL_GetTick(), ret);
  }
#endif


  /********** CORE SYSTEM STARTUP COMPLETE **********/
  SYS_LOG(LOG_INFO, SYS, SYS_READY);
  DEBUG_MSG("[%8lu] [ OK] CORE SYSTEM STARTUP COMPLETE\r\n", HAL_GetTick());

  HAL_TIM_Base_Start_IT(&htim1); // start 100ms periodic timer

  /* USER CODE END 2 */

  /* Infinite loop */
  /* USER CODE BEGIN WHILE */
  while (1) {
    /* check flags */
    // system monitor: core temperature and input voltage
    if (adc_flag & (1 << FLAG_ADC_SYS)) {
      adc_flag &= ~(1 << FLAG_ADC_SYS);

      *(uint16_t *)(syslog.value + 0) = (uint16_t)adc_sys_value[0];
      *(uint16_t *)(syslog.value + 2) = (uint16_t)adc_sys_value[1];
      SYS_LOG(LOG_INFO, ANALOG, ANALOG_SYS);
    }

#ifdef ENABLE_MONITOR_ANALOG
    if (adc_flag & (1 << FLAG_ADC_AIN)) {
      adc_flag &= ~(1 << FLAG_ADC_AIN);

      *(uint16_t *)(syslog.value + 0) = (uint16_t)adc_ain_value[0];
      *(uint16_t *)(syslog.value + 2) = (uint16_t)adc_ain_value[1];
      *(uint16_t *)(syslog.value + 4) = (uint16_t)adc_ain_value[2];
      *(uint16_t *)(syslog.value + 6) = (uint16_t)adc_ain_value[3];
      SYS_LOG(LOG_INFO, ANALOG, ANALOG_DATA);
    }
#endif

#ifdef ENABLE_MONITOR_PULSE
    if (pulse_flag & (1 << PULSE_SET)) {
      // x10 us
      *(uint16_t *)(syslog.value + 0) = (uint16_t)(pulse_value[PULSE_CH0] / 10);
      *(uint16_t *)(syslog.value + 2) = (uint16_t)(pulse_value[PULSE_CH1] / 10);
      *(uint16_t *)(syslog.value + 4) = (uint16_t)(pulse_value[PULSE_CH2] / 10);
      *(uint16_t *)(syslog.value + 6) = (uint16_t)(pulse_value[PULSE_CH3] / 10);
      SYS_LOG(LOG_INFO, PULSE, PULSE_DATA);

      pulse_flag = 0;
    }
#endif

#ifdef ENABLE_MONITOR_ACCELEROMETER
    if (accelerometer_flag == true) {
      accelerometer_flag = false;

      *(uint64_t *)syslog.value = *(uint64_t *)accelerometer_value;
      SYS_LOG(LOG_INFO, ACCELEROMETER, ACCELEROMETER_DATA);
    }
#endif

#ifdef ENABLE_MONITOR_GPS
    if (gps_flag == true) {
      gps_flag = false;
      GPS_PARSE();
    }
#endif

    /* handle recorded LOGs */
    SD_WRITE();

#ifdef ENABLE_SERIAL
    SERIAL_TRANSMIT_LOG();
#endif

#ifdef ENABLE_TELEMETRY
    TELEMETRY_TRANSMIT_LOG();
#endif

    /* check timer flags */
    if (timer_flag & (1 << FLAG_TIMER_100ms)) {
      timer_flag &= ~(1 << FLAG_TIMER_100ms);
      TIMER_100ms();
    }

    if (timer_flag & (1 << FLAG_TIMER_1s)) {
      timer_flag &= ~(1 << FLAG_TIMER_1s);
      TIMER_1s();
    }
    /* USER CODE END WHILE */

    /* USER CODE BEGIN 3 */
  }
  /* USER CODE END 3 */
}

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
/* USER CODE BEGIN 4 */
void TIMER_100ms(void) {
#ifdef ENABLE_MONITOR_DIGITAL
  /* record digital input channels */
  syslog.value[0] = !HAL_GPIO_ReadPin(GPIOD, DIN0_Pin);
  syslog.value[1] = !HAL_GPIO_ReadPin(GPIOD, DIN1_Pin);
  syslog.value[2] = !HAL_GPIO_ReadPin(GPIOD, DIN2_Pin);
  syslog.value[3] = !HAL_GPIO_ReadPin(GPIOD, DIN3_Pin);
  syslog.value[4] = !HAL_GPIO_ReadPin(GPIOD, DIN4_Pin);
  syslog.value[5] = !HAL_GPIO_ReadPin(GPIOD, DIN5_Pin);
  syslog.value[6] = !HAL_GPIO_ReadPin(GPIOD, DIN6_Pin);
  syslog.value[7] = !HAL_GPIO_ReadPin(GPIOD, DIN7_Pin);
  SYS_LOG(LOG_INFO, DIGITAL, DIGITAL_DATA);
#endif

#ifdef ENABLE_MONITOR_ANALOG
  /* start analog input channels ADC conversion */
  if (!(adc_flag & (1 << FLAG_ADC_AIN))) {
    HAL_ADC_Start_DMA(&hadc2, adc_ain_value, 4);
  }
#endif

#ifdef ENABLE_MONITOR_PULSE
  PULSE_CAPTURE();
#endif

#ifdef ENABLE_MONITOR_ACCELEROMETER
  /* this takes 30ms EVERY TIME if the module is NOT CONNECTED */
  if (accelerometer_flag == false) {
    HAL_I2C_Mem_Read_IT(I2C_ACCELEROMETER, ACC_I2C_ADDR, 0x32, 1, accelerometer_value, 6);
  }
#endif
}

void TIMER_1s(void) {
  /* internal temperature and input voltage monitor */
  if (!(adc_flag & (1 << FLAG_ADC_SYS))) {
    HAL_ADC_Start_DMA(&hadc1, adc_sys_value, 2);
  }

  /* SD card sync*/
  SD_SYNC();

  /* heartbeat LED */
  static bool heartbeat = true;
  if (heartbeat) {
    HAL_GPIO_WritePin(GPIOE, LED_HEARTBEAT_Pin, GPIO_PIN_SET);
  } else {
    HAL_GPIO_WritePin(GPIOE, LED_HEARTBEAT_Pin, GPIO_PIN_RESET);
  }
  heartbeat = !heartbeat;
}

#ifdef ENABLE_MONITOR_GPS
void GPS_PARSE(void) {
  static NMEA_GPRMC gprmc;
  static GPS_COORD gps_coord;
  static GPS_VECTOR gps_vector;
  static GPS_DATETIME gps_datetime;

  if (!strncmp((char *)gps_data, "$GPRMC", 6)) {

    // parse NMEA GPRMC sentence
    gprmc.id = gps_data;
    gprmc.utc_time = FIND_AND_NUL(gprmc.id, gprmc.utc_time, ',');
    gprmc.status = FIND_AND_NUL(gprmc.utc_time, gprmc.status, ',');

    // proceed only if GPS fix is valid
    if (*gprmc.status == 'A') {
      gprmc.lat = FIND_AND_NUL(gprmc.status, gprmc.lat, ',');
      gprmc.north = FIND_AND_NUL(gprmc.lat, gprmc.north, ',');
      gprmc.lon = FIND_AND_NUL(gprmc.north, gprmc.lon, ',');
      gprmc.east = FIND_AND_NUL(gprmc.lon, gprmc.east, ',');
      gprmc.speed = FIND_AND_NUL(gprmc.east, gprmc.speed, ',');
      gprmc.course = FIND_AND_NUL(gprmc.speed, gprmc.course, ',');
      gprmc.utc_date = FIND_AND_NUL(gprmc.course, gprmc.utc_date, ',');
      gprmc.others = FIND_AND_NUL(gprmc.utc_date, gprmc.others, ',');

      // process GPS coordinates
      gps_coord.lat = to_uint(gprmc.lat, '.');
      gps_coord.lon = to_uint(gprmc.lon, '.');

      // process GPS speed and course
      gps_vector.speed = (int)(atof((char *)gprmc.speed) * 100);
      gps_vector.course = drop_point(gprmc.course);

      // process GPS datetime
      gps_datetime.utc_date = atoi((char *)gprmc.utc_date);
      gps_datetime.utc_time = drop_point(gprmc.utc_time);

      *(uint64_t *)syslog.value = *(uint64_t *)&gps_coord;
      SYS_LOG(LOG_INFO, GPS, GPS_POS);

      *(uint64_t *)syslog.value = *(uint64_t *)&gps_vector;
      SYS_LOG(LOG_INFO, GPS, GPS_VEC);

      *(uint64_t *)syslog.value = *(uint64_t *)&gps_datetime;
      SYS_LOG(LOG_INFO, GPS, GPS_TIME);
    }
  }
}
#endif
/* USER CODE END 4 */
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


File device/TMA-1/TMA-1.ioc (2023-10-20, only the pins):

Mcu.UserName=STM32F407VETx
PA0-WKUP.GPIO_Label=PIN0
PA0-WKUP.Signal=S_TIM5_CH1
PA1.GPIO_Label=PIN1
PA1.Signal=S_TIM5_CH2
PA10.GPIO_Label=USART_DEBUG_RX
PA10.Signal=USART1_RX
PA2.GPIO_Label=PIN2
PA2.Signal=S_TIM5_CH3
PA3.GPIO_Label=PIN3
PA3.Signal=S_TIM5_CH4
PA6.GPIO_Label=LED_ONBOARD_0
PA6.Signal=GPIO_Output
PA7.GPIO_Label=LED_ONBOARD_1
PA7.Signal=GPIO_Output
PA8.GPIO_Label=I2C_ACC_SCL
PA8.Signal=I2C3_SCL
PA9.GPIO_Label=USART_DEBUG_TX
PA9.Signal=USART1_TX
PB12.GPIO_Label=SDIO_DETECT
PB12.Signal=GPIO_Input
PB6.GPIO_Label=I2C_ESP_SCL
PB6.Signal=I2C1_SCL
PB7.GPIO_Label=I2C_ESP_SDA
PB7.Signal=I2C1_SDA
PB8.GPIO_Label=ESP_COMM
PB8.Signal=GPXTI8
PC0.GPIO_Label=AIN0
PC0.Signal=ADCx_IN10
PC1.GPIO_Label=AIN1
PC1.Signal=ADCx_IN11
PC10.GPIO_Label=USART_GPS_TX
PC10.Signal=USART3_TX
PC11.GPIO_Label=USART_GPS_RX
PC11.Signal=USART3_RX
PC12.Signal=SDIO_CK
PC14-OSC32_IN.Signal=RCC_OSC32_IN
PC15-OSC32_OUT.Signal=RCC_OSC32_OUT
PC2.GPIO_Label=AIN2
PC2.Signal=ADCx_IN12
PC3.GPIO_Label=AIN3
PC3.Signal=ADCx_IN13
PC5.GPIO_Label=Vsense
PC5.Signal=ADCx_IN15
PC6.GPIO_Label=USART_LOG_TX
PC6.Signal=USART6_TX
PC7.GPIO_Label=USART_LOG_RX
PC7.Signal=USART6_RX
PC8.Signal=SDIO_D0
PC9.GPIO_Label=I2C_ACC_SDA
PC9.Signal=I2C3_SDA
PD0.Signal=CAN1_RX
PD1.Signal=CAN1_TX
PD10.GPIO_Label=DIN2
PD10.Signal=GPIO_Input
PD11.GPIO_Label=DIN3
PD11.Signal=GPIO_Input
PD12.GPIO_Label=DIN4
PD12.Signal=GPIO_Input
PD13.GPIO_Label=DIN5
PD13.Signal=GPIO_Input
PD14.GPIO_Label=DIN6
PD14.Signal=GPIO_Input
PD15.GPIO_Label=DIN7
PD15.Signal=GPIO_Input
PD2.Signal=SDIO_CMD
PD8.GPIO_Label=DIN0
PD8.Signal=GPIO_Input
PD9.GPIO_Label=DIN1
PD9.Signal=GPIO_Input
PE10.GPIO_Label=LED_CUSTOM_1
PE10.Signal=GPIO_Output
PE11.GPIO_Label=LED_ERR
PE11.Signal=GPIO_Output
PE12.GPIO_Label=LED_HEARTBEAT
PE12.Signal=GPIO_Output
PE13.GPIO_Label=LED_SD
PE13.Signal=GPIO_Output
PE14.GPIO_Label=LED_CAN
PE14.Signal=GPIO_Output
PE15.GPIO_Label=LED_TELEMETRY
PE15.Signal=GPIO_Output
PE9.GPIO_Label=LED_CUSTOM_0
PE9.Signal=GPIO_Output
PH0-OSC_IN.Signal=RCC_OSC_IN
PH1-OSC_OUT.Signal=RCC_OSC_OUT

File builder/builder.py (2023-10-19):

import os
import sys
import json
import shutil
import subprocess
import serial.tools.list_ports

import toolchain

# spawn a subprocess
def spawn(argv):
    p = subprocess.Popen(argv, encoding='utf-8', stdout=subprocess.PIPE, stderr=subprocess.STDOUT, universal_newlines=True)
    while p.poll() == None:
        try:
            print(p.stdout.readline(), end='')
        except UnicodeDecodeError:
            pass

    return p.poll()


##### STM32 build and flash process START #####
def build_stm32():
    print("INFO: building TMA-1 STM32 binary...")

    # set build environment variables
    with open("./config/build_config.json", "r") as file:
        build_config = json.load(file)

        os.environ["ENABLE_TELEMETRY"] = '1' if build_config["STM32"]["output"]["telemetry"] else '0'
        os.environ["ENABLE_SERIAL"]    = '1' if build_config["STM32"]["output"]["serial"] else '0'

        os.environ["ENABLE_MONITOR_CAN"]           = '1' if build_config["STM32"]["sensor"]["can"] else '0'
        os.environ["ENABLE_MONITOR_DIGITAL"]       = '1' if build_config["STM32"]["sensor"]["digital"] else '0'
        os.environ["ENABLE_MONITOR_ANALOG"]        = '1' if build_config["STM32"]["sensor"]["analog"] else '0'
        os.environ["ENABLE_MONITOR_PULSE"]         = '1' if build_config["STM32"]["sensor"]["pulse"] else '0'
        os.environ["ENABLE_MONITOR_ACCELEROMETER"] = '1' if build_config["STM32"]["sensor"]["accelerometer"] else '0'
        os.environ["ENABLE_MONITOR_GPS"]           = '1' if build_config["STM32"]["sensor"]["gps"] else '0'

        os.environ["DEBUG_MODE"] = '1' if build_config["STM32"]["debug"]["debug_mode"] else '0'

        os.environ["DEBUG"] = '0' if build_config["STM32"]["debug"]["release_build"] else '1'
        os.environ["OPT"] = '-O2' if build_config["STM32"]["debug"]["release_build"] else '-Og'

        if build_config["STM32"]["can"]["baudrate"] == '125 kbit/s':
            os.environ["CAN_PRESC"] = "21"
            os.environ["CAN_TSEG1"] = "CAN_BS1_13TQ"

        elif build_config["STM32"]["can"]["baudrate"] == '250 kbit/s':
            os.environ["CAN_PRESC"] = "12"
            os.environ["CAN_TSEG1"] = "CAN_BS1_11TQ"

        elif build_config["STM32"]["can"]["baudrate"] == '500 kbit/s':
            os.environ["CAN_PRESC"] = "6"
            os.environ["CAN_TSEG1"] = "CAN_BS1_11TQ"

        elif build_config["STM32"]["can"]["baudrate"] == '1 Mbit/s':
            os.environ["CAN_PRESC"] = "3"
            os.environ["CAN_TSEG1"] = "CAN_BS1_11TQ"

    # step into STM32CubeMX project folder
    os.chdir('../device/TMA-1')

    # build
    ret = spawn(['make'])

    # step back to builder
    os.chdir('../../builder')

    if ret != 0:
        print("\nERROR: build job failed. terminating.")
        return -1

    # move target executable
    if os.path.exists('../device/TMA-1/build/TMA-1.elf'):
        os.makedirs('./build', exist_ok=True)
        shutil.copyfile('../device/TMA-1/build/TMA-1.elf', './build/TMA-1.elf')
        print("INFO: build of TMA-1 STM32 binary completed! binary copied to build/TMA-1.elf")
        return 0

    else:
        print("\nERROR: No binary found for STM32. terminating.")
        return -1


def flash_stm32():
    print("INFO: flashing TMA-1 STM32 binary...")

    retry = 0
    ret = spawn(['openocd', '-f', './config/TMA-1.cfg'])

    while ret != 0 and retry < 2:
        retry += 1
        print(f"ERROR: flashing failed. retry count: {retry}")
        ret = spawn(['openocd', '-f', './config/TMA-1.cfg'])

    if ret != 0:
        print("ERROR: max retry count reached. terminating.")
        return -1

    print('INFO: TMA-1 STM32 binary successfully flashed. please recyle the power.')
    return 0
##### STM32 build and flash process END #####


##### ESP32 build and flash process START #####
def build_esp32():
    print("INFO: building TMA-1 ESP32 binary...")

    # set build environment variables
    with open("./config/build_config.json", "r") as file:
        build_config = json.load(file)

    ret = spawn(['arduino-cli', '--config-file', './config/arduino-cli.yaml', 'compile', '-e', '--fqbn', 'esp32:esp32:esp32', '-v', '--build-property', f'compiler.cpp.extra_flags="-DNETWORK_SSID="{build_config["ESP32"]["network"]["ssid"]}"" -DNETWORK_PASSWORD="{build_config["ESP32"]["network"]["password"]}" -DCHANNEL_NAME="{build_config["ESP32"]["channel"]["name"]}" -DCHANNEL_KEY="{build_config["ESP32"]["channel"]["key"]}" -DSERVER_NAME="{build_config["ESP32"]["server"]["name"]}"', '../device/telemetry/telemetry.ino'])

    if ret != 0:
        print("\nERROR: build job failed. terminating.")
        return -1

    # move target executable
    if os.path.exists('../device/telemetry/build/esp32.esp32.esp32/telemetry.ino.elf'):
        os.makedirs('./build', exist_ok=True)
        shutil.copyfile('../device/telemetry/build/esp32.esp32.esp32/telemetry.ino.elf', './build/telemetry.elf')
        shutil.copyfile('../device/telemetry/build/esp32.esp32.esp32/telemetry.ino.bin', './build/telemetry.bin')
        shutil.copyfile('../device/telemetry/build/esp32.esp32.esp32/telemetry.ino.map', './build/telemetry.map')
        shutil.copyfile('../device/telemetry/build/esp32.esp32.esp32/telemetry.ino.bootloader.bin', './build/telemetry.bootloader.bin')
        shutil.copyfile('../device/telemetry/build/esp32.esp32.esp32/telemetry.ino.partitions.bin', './build/telemetry.partitions.bin')
        print("INFO: build of TMA-1 ESP32 binary completed! binary copied to build/telemetry.*")
        return 0

    print("INFO: build of TMA-1 ESP32 binary completed!")
    return 0

def flash_esp32():
    print("INFO: flashing TMA-1 ESP32 binary...")

    # set build environment variables
    port = None
    with open("./config/build_config.json", "r") as file:
        build_config = json.load(file)
        port = build_config["ESP32"]["port"]

    # auto-detect esp32 port
    if port == "":
        for p in serial.tools.list_ports.comports():
            if p.vid == 0x10C4 and p.pid == 0xEA60:
                port = p.name
                break

    # auto-detect failure
    if port == "":
        print("ERROR: no ESP32 found! please check connection or specify the COM port in the Configuration Tool.")
        return -1

    ret = spawn(['arduino-cli', '--config-file', './config/arduino-cli.yaml', 'upload', '-i', './build/telemetry.elf', '--fqbn', 'esp32:esp32:esp32', '-p', port ])

    if ret != 0:
        print("ERROR: flashing failed. terminating.")
        return -1

    print('INFO: TMA-1 ESP32 binary successfully flashed. please recyle the power.')
    return 0
##### ESP32 build and flash process END #####
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

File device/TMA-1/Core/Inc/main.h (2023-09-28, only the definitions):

#define AIN0_Pin GPIO_PIN_0
#define AIN0_GPIO_Port GPIOC
#define AIN1_Pin GPIO_PIN_1
#define AIN1_GPIO_Port GPIOC
#define AIN2_Pin GPIO_PIN_2
#define AIN2_GPIO_Port GPIOC
#define AIN3_Pin GPIO_PIN_3
#define AIN3_GPIO_Port GPIOC
#define PIN0_Pin GPIO_PIN_0
#define PIN0_GPIO_Port GPIOA
#define PIN1_Pin GPIO_PIN_1
#define PIN1_GPIO_Port GPIOA
#define PIN2_Pin GPIO_PIN_2
#define PIN2_GPIO_Port GPIOA
#define PIN3_Pin GPIO_PIN_3
#define PIN3_GPIO_Port GPIOA
#define LED_ONBOARD_0_Pin GPIO_PIN_6
#define LED_ONBOARD_0_GPIO_Port GPIOA
#define LED_ONBOARD_1_Pin GPIO_PIN_7
#define LED_ONBOARD_1_GPIO_Port GPIOA
#define Vsense_Pin GPIO_PIN_5
#define Vsense_GPIO_Port GPIOC
#define LED_CUSTOM_0_Pin GPIO_PIN_9
#define LED_CUSTOM_0_GPIO_Port GPIOE
#define LED_CUSTOM_1_Pin GPIO_PIN_10
#define LED_CUSTOM_1_GPIO_Port GPIOE
#define LED_ERR_Pin GPIO_PIN_11
#define LED_ERR_GPIO_Port GPIOE
#define LED_HEARTBEAT_Pin GPIO_PIN_12
#define LED_HEARTBEAT_GPIO_Port GPIOE
#define LED_SD_Pin GPIO_PIN_13
#define LED_SD_GPIO_Port GPIOE
#define LED_CAN_Pin GPIO_PIN_14
#define LED_CAN_GPIO_Port GPIOE
#define LED_TELEMETRY_Pin GPIO_PIN_15
#define LED_TELEMETRY_GPIO_Port GPIOE
#define SDIO_DETECT_Pin GPIO_PIN_12
#define SDIO_DETECT_GPIO_Port GPIOB
#define DIN0_Pin GPIO_PIN_8
#define DIN0_GPIO_Port GPIOD
#define DIN1_Pin GPIO_PIN_9
#define DIN1_GPIO_Port GPIOD
#define DIN2_Pin GPIO_PIN_10
#define DIN2_GPIO_Port GPIOD
#define DIN3_Pin GPIO_PIN_11
#define DIN3_GPIO_Port GPIOD
#define DIN4_Pin GPIO_PIN_12
#define DIN4_GPIO_Port GPIOD
#define DIN5_Pin GPIO_PIN_13
#define DIN5_GPIO_Port GPIOD
#define DIN6_Pin GPIO_PIN_14
#define DIN6_GPIO_Port GPIOD
#define DIN7_Pin GPIO_PIN_15
#define DIN7_GPIO_Port GPIOD
#define USART_LOG_TX_Pin GPIO_PIN_6
#define USART_LOG_TX_GPIO_Port GPIOC
#define USART_LOG_RX_Pin GPIO_PIN_7
#define USART_LOG_RX_GPIO_Port GPIOC
#define I2C_ACC_SDA_Pin GPIO_PIN_9
#define I2C_ACC_SDA_GPIO_Port GPIOC
#define I2C_ACC_SCL_Pin GPIO_PIN_8
#define I2C_ACC_SCL_GPIO_Port GPIOA
#define USART_DEBUG_TX_Pin GPIO_PIN_9
#define USART_DEBUG_TX_GPIO_Port GPIOA
#define USART_DEBUG_RX_Pin GPIO_PIN_10
#define USART_DEBUG_RX_GPIO_Port GPIOA
#define USART_GPS_TX_Pin GPIO_PIN_10
#define USART_GPS_TX_GPIO_Port GPIOC
#define USART_GPS_RX_Pin GPIO_PIN_11
#define USART_GPS_RX_GPIO_Port GPIOC
#define I2C_ESP_SCL_Pin GPIO_PIN_6
#define I2C_ESP_SCL_GPIO_Port GPIOB
#define I2C_ESP_SDA_Pin GPIO_PIN_7
#define I2C_ESP_SDA_GPIO_Port GPIOB
#define ESP_COMM_Pin GPIO_PIN_8
#define ESP_COMM_GPIO_Port GPIOB
#define ESP_COMM_EXTI_IRQn EXTI9_5_IRQn

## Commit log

2023-09-06 add: STM32CubeMX TMA-1 project
2023-09-07 fix: build project on STM32CubeIDE
    [main.c]
2023-09-07 add: builder prototype
    [TMA-1.cfg]
2023-09-08 improve: builder code formats
    improve: builder code formats
    [TMA-1.cfg]
2023-09-08 update: openocd flash command
    [TMA-1.cfg, stm32f4x.cfg]
2023-09-08 enable: onboard LED
2023-09-08 improve: stm32 flashing process
    improve: stm32 build process
    [TMA-1.cfg]
2023-09-14 add: 100ms timer tick update
2023-09-15 remove: timer 500ms periodic event
2023-09-15 add: analog input with DMA support
2023-09-15 add: pulse timer input capture support
2023-09-15 add: ADXL345 accelerometer support
2023-09-16 disable: UART2 for ESP32 communication
2023-09-17 enable: ESP32 communication EXTI
2023-09-18 refactor: ESP32 handshake protocol using I2C and EXTI
2023-09-19 update: configuration tool prototype
2023-09-20 fix: build with enabled features
    [builder.py, can.c, gpio.c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]
2023-09-20 add: send time via uart
2023-09-20 improve: serial time sync error handling
    [main.py]
2023-09-21 improve: misc configuration tool UI fix
    [main.py]
2023-09-21 fix: build configuration update bug
    delete: unused file
    [builder.py, main.py]
2023-09-21 fix: RTC string parsing and backup bug
    [main.c, rtc.c]
2023-09-21 fix: OpenOCD stlink soft reset bug
    [TMA-1.cfg]
2023-09-21 improve: add clean button and incremental build as default
2023-09-21 rename: ESP32 code
2023-09-22 add: schematic and artwork prototype
    [TMA-1.kicad_pcb, TMA-1.kicad_sch]
2023-09-22 update: complete PCB artwork
    [TMA-1.kicad_pcb, TMA-1.kicad_sch]
2023-09-23 add: PCB v1.0 gerber files
    [TMA-1-B_Cu.gbr, TMA-1-B_Mask.gbr, TMA-1-B_Paste.gbr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]
2023-09-23 fix: missing solder mask at STM32 holder
    [TMA-1-B_Cu.gbr, TMA-1-B_Mask.gbr, TMA-1-B_Paste.gbr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]
2023-09-26 improve: pin name silkscreen
    [TMA-1-B_Cu.gbr, TMA-1-B_Mask.gbr, TMA-1-B_Paste.gbr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]
2023-09-26 improve: PCB v1.1 add debug uart jumper
    [TMA-1-B_Cu.gbr, TMA-1-B_Mask.gbr, TMA-1-B_Paste.gbr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]
2023-09-26 update: TELEMETRY LED manipulation at server connect/disconnect
2023-09-27 update: telemetry device authorize parameters
2023-09-27 add: TMA-2 server prototype
2023-09-28 fix: config tool behavior at build failure
    [builder.py]
2023-09-28 fix: ADC conversion timing bug
    [TMA-1.ioc, adc.c]
2023-09-28 fix: disable ESP32 watchdog timer for core 0
    [telemetry.ino]
2023-09-28 fix: 2 critical bugs in telemetry
    TELEMETETRY_BUFFER_ARR overflow
    I2C bus busy on RTC fix
    [gpio.c, i2c.c]
2023-09-28 fix: I2C timeout error at LOW ESP_COMM
    [gpio.c, i2c.c]
2023-09-29 fix: ADC DMA transfer data width
    [TMA-1.ioc, adc.c]
2023-10-12 improve: ESP32 handshake process stability
    [i2c.c]
2023-10-13 add: server config samples
2023-10-13 add: client side telemetry indicator timer
2023-10-13 fix: always flush i2c buffer
    [telemetry.ino]
2023-10-13 fix: invert digital input channels
    [main.c]
2023-10-14 add: ESP32 build and flash process
2023-10-14 add: ESP32 build with build_config.json
2023-10-14 improve: ESP32 build system
2023-10-14 improve: print ESP32 configuration at startup
2023-10-14 fix: toolchain validation bug
    [toolchain.py]
2023-10-14 fix: disable core separation for event and main routine
    [builder.py]
2023-10-14 fix: misc bugs PCB v1.2
    [TMA-1-B_Cu.gbr, TMA-1-B_Mask.gbr, TMA-1-B_Paste.gbr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]
2023-10-16 improve: arduino-cli download directory to .cache
2023-10-16 upgrade: ARM GNU Toolchain
2023-10-16 fix: not receiving GPS bug
    [usart.c]
2023-10-17 improve: GPS measure rate to 10Hz from 1Hz
2023-10-17 improve: TELEMETRY LED flashing 3 times on ESP init
2023-10-17 update: unify rtc fix log
    [rtc.c]
2023-10-17 improve: detailed ESP init failure log
    [i2c.c, types.h]
2023-10-20 fix: some STM32 build issues
    undefined reference to to_uint() and drop_point()
    syscall.c will always fail
    remove unnecessary files
    [TMA-1.ioc, main.c]
2024-05-23 add: CI kicad image generation
2024-05-23 improve: cache kicad installation
2024-05-23 remove: kicad caching on CI
2024-07-18 update: pin esp32-arduino core and library versions, use stable arduino-cli
2024-10-11 build(deps): bump cookie and socket.io in /server
    Bumps [cookie](https://github.com/jshttp/cookie) to 0.7.2 and updates ancestor dependency [socket.io](https://github.com/socketio/socket.io). These dependencies need to be updated together.
    Updates `cookie` from 0.4.2 to 0.7.2
    - [Release notes](https://github.com/jshttp/cookie/releases)
    - [Commits](https://github.com/jshttp/cookie/compare/v0.4.2...v0.7.2)
    Updates `socket.io` from 4.7.5 to 4.8.0
    - [Release notes](https://github.com/socketio/socket.io/releases)
    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
2026-07-03 fix: keep telemetry running without SD card
    [main.h, sdcard.c]
2026-07-03 fix: avoid sd log queue without writer
    [main.h, sdcard.c]
2026-07-03 fix: guard telemetry queue restore paths
    [main.h, sdcard.c]

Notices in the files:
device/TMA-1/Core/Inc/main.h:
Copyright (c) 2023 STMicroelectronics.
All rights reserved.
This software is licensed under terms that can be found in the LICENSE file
